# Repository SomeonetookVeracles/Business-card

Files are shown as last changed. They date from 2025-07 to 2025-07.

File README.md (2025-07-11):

# Business-card
A PCB business card with a USB-C port and HID, so when you press the button it auto opens a link to the website encoded on it.
I feel like in tech you really need to stand out when it comes to how you spread your information, so I decided to create a twist on the standard business card design by creating a HID business card to make employers expend that little bit of effort to remember me by.







### Bill of Materials

## Bill of Materials (BOM)

| Reference | Qty | Value | DNP | Exclude from BOM | Exclude from Board | Footprint | Datasheet/Purchase Links |
|---|-----|---|-----|---|---|---|---|
| C1, C2, C3, C4 | 4 | 1uF | | | | Capacitor_SMD:C_0201_0603Metric | [DigiKey 1µF 0603](https://www.digikey.com/en/products/detail/yageo/CC0603ZRY5V7BB105/2103110) • [Mouser 1µF 0603](https://www.mouser.com/c/passive-components/capacitors/ceramic-capacitors/mlccs-multilayer-ceramic-capacitors/multilayer-ceramic-capacitors-mlcc-smd-smt/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) • [LCSC Capacitors](https://lcsc.com/products/Capacitors_312.html) |
| C5 | 1 | 10uF | | | | Capacitor_SMD:C_0201_0603Metric | [DigiKey 10µF 0603](https://www.digikey.com/en/products/filter/ceramic-capacitors/60) • [Mouser 10µF](https://www.mouser.com/c/passive-components/capacitors/) • [LCSC Capacitors](https://lcsc.com/products/Capacitors_312.html) |
| C6, C7 | 2 | 22pF | | | | Capacitor_SMD:C_0201_0603Metric | [DigiKey 22pF 0603](https://www.digikey.com/en/products/filter/ceramic-capacitors/60) • [Mouser 22pF](https://www.mouser.com/c/passive-components/capacitors/) • [LCSC Capacitors](https://lcsc.com/products/Capacitors_312.html) |
| J3 | 1 | USB_C_Receptacle | | | | Connector_USB:USB_C_Receptacle_Amphenol_12401548E4-2A | [DigiKey 12401548E4#2A](https://www.digikey.com/en/products/detail/amphenol-cs-commercial-products/12401548E4-2A/5318158) • [USB Type-C Spec](https://www.usb.org/sites/default/files/documents/usb_type-c.zip) |
| R1 | 1 | 10k | | | | Resistor_SMD:R_0402_1005Metric_Pad0.72x0.64mm_HandSolder | [DigiKey 10kΩ 0402](https://www.digikey.com/en/products/filter/chip-resistor-surface-mount/52) • [Mouser 10kΩ](https://www.mouser.com/c/passive-components/resistors/) • [LCSC Resistors](https://lcsc.com/products/Chip-Resistor-Surface-Mount_439.html) |
| R2, R3 | 2 | 22 | | | | Resistor_SMD:R_0201_0603Metric | [DigiKey 22Ω 0603](https://www.digikey.com/en/products/filter/chip-resistor-surface-mount/52) • [Mouser 22Ω](https://www.mouser.com/c/passive-components/resistors/) • [LCSC Resistors](https://lcsc.com/products/Chip-Resistor-Surface-Mount_439.html) |
| R4, R5, R6, R7 | 4 | 10k | | | | Resistor_SMD:R_0201_0603Metric | [DigiKey 10kΩ 0603](https://www.digikey.com/en/products/filter/chip-resistor-surface-mount/52) • [Mouser 10kΩ](https://www.mouser.com/c/passive-components/resistors/) • [LCSC Resistors](https://lcsc.com/products/Chip-Resistor-Surface-Mount_439.html) |
| R11, R12 | 2 | 5.1k | | | | Resistor_SMD:R_0201_0603Metric | [DigiKey 5.1kΩ 0603](https://www.digikey.com/en/products/filter/chip-resistor-surface-mount/52) • [Mouser 5.1kΩ](https://www.mouser.com/c/passive-components/resistors/) • [LCSC Resistors](https://lcsc.com/products/Chip-Resistor-Surface-Mount_439.html) |
| RST1 | 1 | SW_Push | | | | Button_Switch_SMD:SW_Push_1P1T_NO_CK_KMR2 | [DigiKey KMR221GLFS](https://www.digikey.com/en/products/detail/c-k/KMR221GLFS/550472) • [Mouser KMR221GLFS](https://www.mouser.com/ProductDetail/CK/KMR221GLFS?qs=sb%2But3Lm4x2RtkMQYdEYMA%3D%3D) • [C&K KMR2 Series](https://www.ckswitches.com/products/switches/product-details/Tactile/KMR2/) |
| SW1, SW2, SW3 | 3 | SW_Omron_B3FS | | | | Button_Switch_SMD:SW_SPST_Omron_B3FS-100xP | [DigiKey B3FS-1000P](https://www.digikey.com/en/products/detail/omron-electronics-inc-emc-div/B3FS-1000P/277814) • [Mouser B3FS Series](https://www.mouser.com/new/omron-electronics/omronB3FS4/) • [Omron B3FS Datasheet](https://omronfs.omron.com/en_US/ecb/products/pdf/en-b3fs.pdf) |
| U1 | 1 | ATmega32U4-A | | | | Package_QFP:TQFP-44_10x10mm_P0.8mm | [DigiKey ATMEGA32U4-AU](https://www.digikey.com/en/products/detail/microchip-technology/ATMEGA32U4-AU/1914602) • [Mouser ATMEGA32U4-AUR](https://www.mouser.com/ProductDetail/Microchip-Technology/ATMEGA32U4-AUR?qs=rBGENRD8NwIbVIAimLns%252BA%3D%3D) • [ATmega32U4 Datasheet](http://ww1.microchip.com/downloads/en/DeviceDoc/Atmel-7766-8-bit-AVR-ATmega16U4-32U4_Datasheet.pdf) |
| Y1 | 1 | Crystal_GND24_Small| | | | Crystal:Crystal_SMD_0603-4Pin_6.0x3.5mm | [DigiKey 16MHz Crystal](https://www.digikey.com/en/products/detail/txc-corporation/7V-16-000MAAE-T/2626978) • [Mouser 16MHz SMD](https://www.mouser.com/c/passive-components/frequency-control-timing-devices/crystals/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) • [LCSC Crystals](https://lcsc.com/products) |

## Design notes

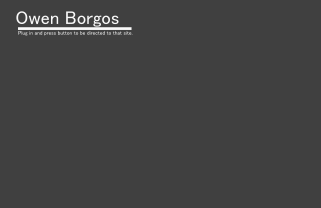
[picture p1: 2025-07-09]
Kicad Layer 1.png

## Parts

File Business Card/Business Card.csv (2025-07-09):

Reference | Qty | Value | DNP | Exclude from BOM | Exclude from Board | Footprint | Datasheet
C1,C2,C3,C4 | 4 | 1uF |  |  |  | Capacitor_SMD:C_0201_0603Metric | ~
C5 | 1 | 10uF |  |  |  | Capacitor_SMD:C_0201_0603Metric | ~
C6,C7 | 2 | 22pF |  |  |  | Capacitor_SMD:C_0201_0603Metric | ~
J3 | 1 | USB_C_Receptacle |  |  |  | Connector_USB:USB_C_Receptacle_Amphenol_12401548E4-2A | https://www.usb.org/sites/default/files/documents/usb_type-c.zip
R1 | 1 | 10k |  |  |  | Resistor_SMD:R_0402_1005Metric_Pad0.72x0.64mm_HandSolder | ~
R2,R3 | 2 | 22 |  |  |  | Resistor_SMD:R_0201_0603Metric | ~
R4,R5,R6,R7 | 4 | 10k |  |  |  | Resistor_SMD:R_0201_0603Metric | ~
R11,R12 | 2 | 5.1k |  |  |  | Resistor_SMD:R_0201_0603Metric | ~
RST1 | 1 | SW_Push |  |  |  | Button_Switch_SMD:SW_Push_1P1T_NO_CK_KMR2 | ~
SW1,SW2,SW3 | 3 | SW_Omron_B3FS |  |  |  | Button_Switch_SMD:SW_SPST_Omron_B3FS-100xP | https://omronfs.omron.com/en_US/ecb/products/pdf/en-b3fs.pdf
U1 | 1 | ATmega32U4-A |  |  |  | Package_QFP:TQFP-44_10x10mm_P0.8mm | http://ww1.microchip.com/downloads/en/DeviceDoc/Atmel-7766-8-bit-AVR-ATmega16U4-32U4_Datasheet.pdf
Y1 | 1 | Crystal_GND24_Small |  |  |  | Crystal:Crystal_SMD_0603-4Pin_6.0x3.5mm | ~

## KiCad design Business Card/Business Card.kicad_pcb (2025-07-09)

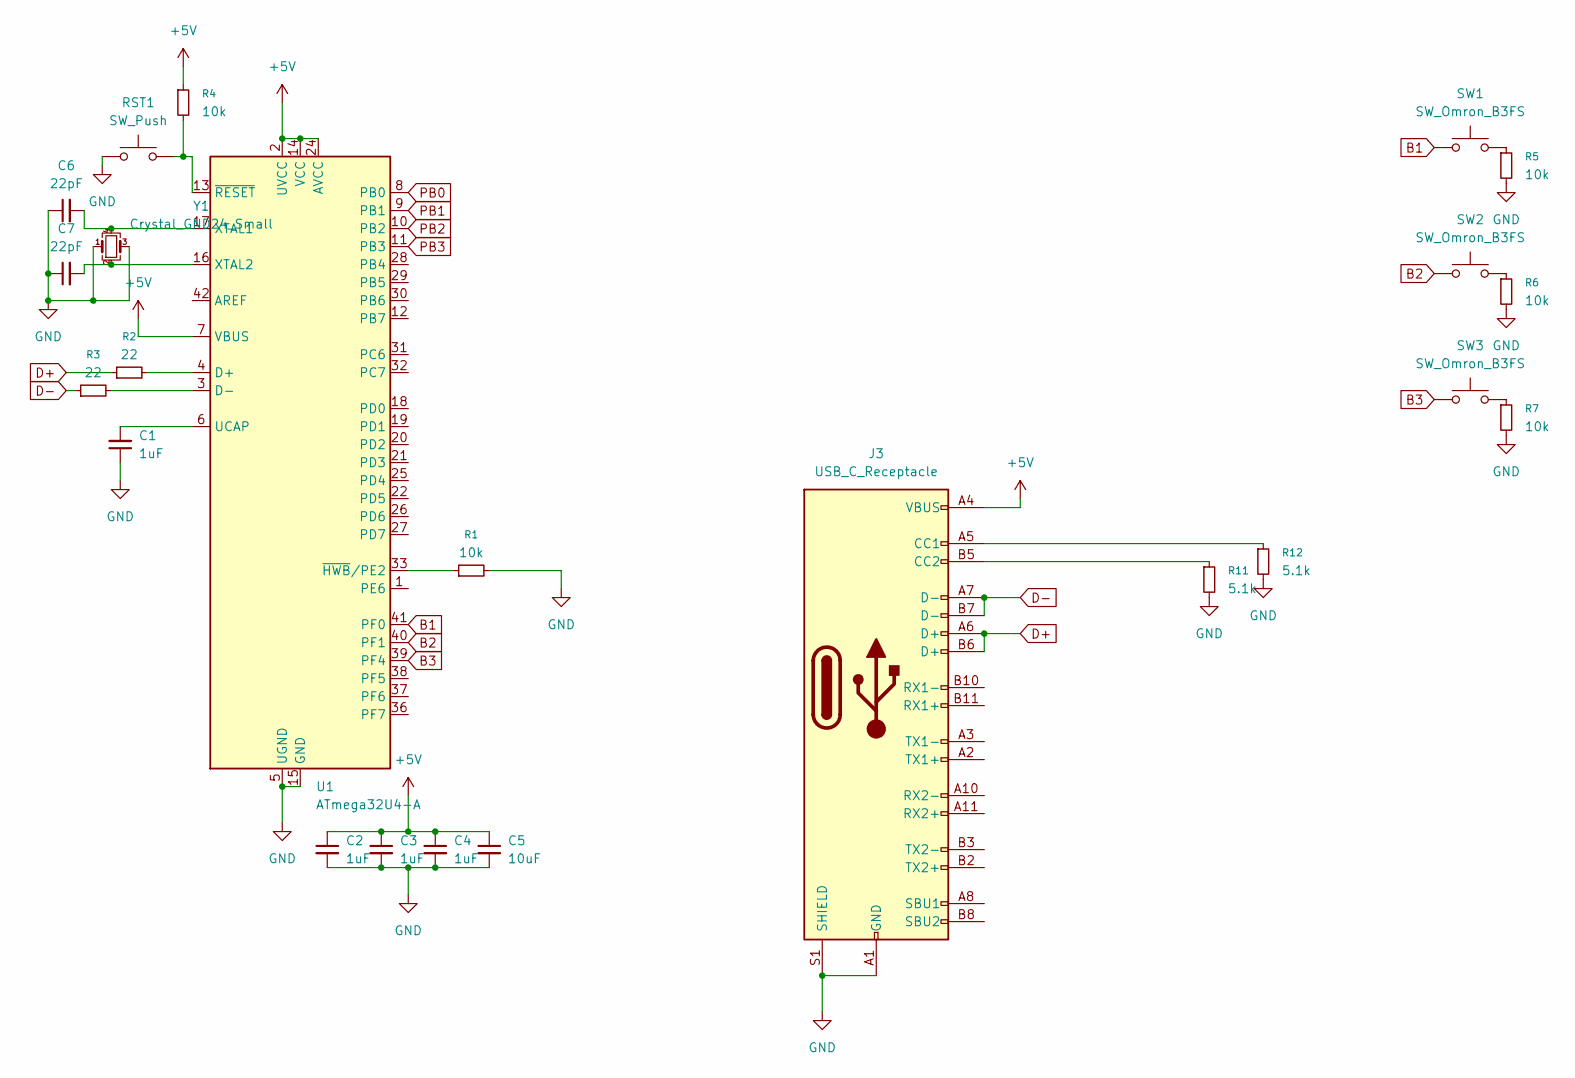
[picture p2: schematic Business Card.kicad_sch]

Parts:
C1, C2, C3, C4: 1uF; C_0201_0603Metric
C5: 10uF; C_0201_0603Metric
C6, C7: 22pF; C_0201_0603Metric
J3: USB_C_Receptacle; USB_C_Receptacle_Amphenol_12401548E4-2A
R1: 10k; R_0402_1005Metric_Pad0.72x0.64mm_HandSolder
R2, R3: 22; R_0201_0603Metric
R4, R5, R6, R7: 10k; R_0201_0603Metric
R11, R12: 5.1k; R_0201_0603Metric
RST1: SW_Push; SW_Push_1P1T_NO_CK_KMR2
SW1, SW2, SW3: SW_Omron_B3FS; SW_SPST_Omron_B3FS-100xP
U1: ATmega32U4-A; TQFP-44_10x10mm_P0.8mm
Y1: Crystal_GND24_Small; Crystal_SMD_0603-4Pin_6.0x3.5mm

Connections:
+5V: C2.1, C3.1, C4.1, C5.1, J3.A4 (VBUS), J3.A9 (VBUS), J3.B4 (VBUS), J3.B9 (VBUS), R4.1, U1.2 (UVCC), U1.7 (VBUS), U1.14 (VCC), U1.24 (AVCC), U1.34 (VCC), U1.44 (AVCC)
B1: SW1.1, U1.41 (PF0)
B2: SW2.1, U1.40 (PF1)
B3: SW3.1, U1.39 (PF4)
D+: J3.A6 (D+), J3.B6 (D+), R2.1
D-: J3.A7 (D-), J3.B7 (D-), R3.1
GND: C1.1, C2.2, C3.2, C4.2, C5.2, C6.1, C7.1, J3.A1 (GND), J3.A12 (GND), J3.B1 (GND), J3.B12 (GND), J3.S1 (SHIELD), R1.2, R5.2, R6.2, R7.2, R11.2, R12.2, RST1.1, U1.5 (UGND), U1.15 (GND), U1.23 (GND), U1.35 (GND), U1.43 (GND), Y1.1, Y1.3
unnamed: J3.A5 (CC1), R12.1
unnamed: J3.B5 (CC2), R11.1
unnamed: R5.1, SW1.2
unnamed: R6.1, SW2.2
unnamed: R7.1, SW3.2
unnamed: R2.2, U1.4 (D+)
unnamed: R3.2, U1.3 (D-)
unnamed: C1.2, U1.6 (UCAP)
unnamed: C6.2, U1.17 (XTAL1), Y1.4
unnamed: C7.2, U1.16 (XTAL2), Y1.2
unnamed: R1.1, U1.33 (~HWB/PE2)
unnamed: R4.2, RST1.2, U1.13 (~RESET)
PB0: U1.8 (PB0)
PB1: U1.9 (PB1)
PB2: U1.10 (PB2)
PB3: U1.11 (PB3)

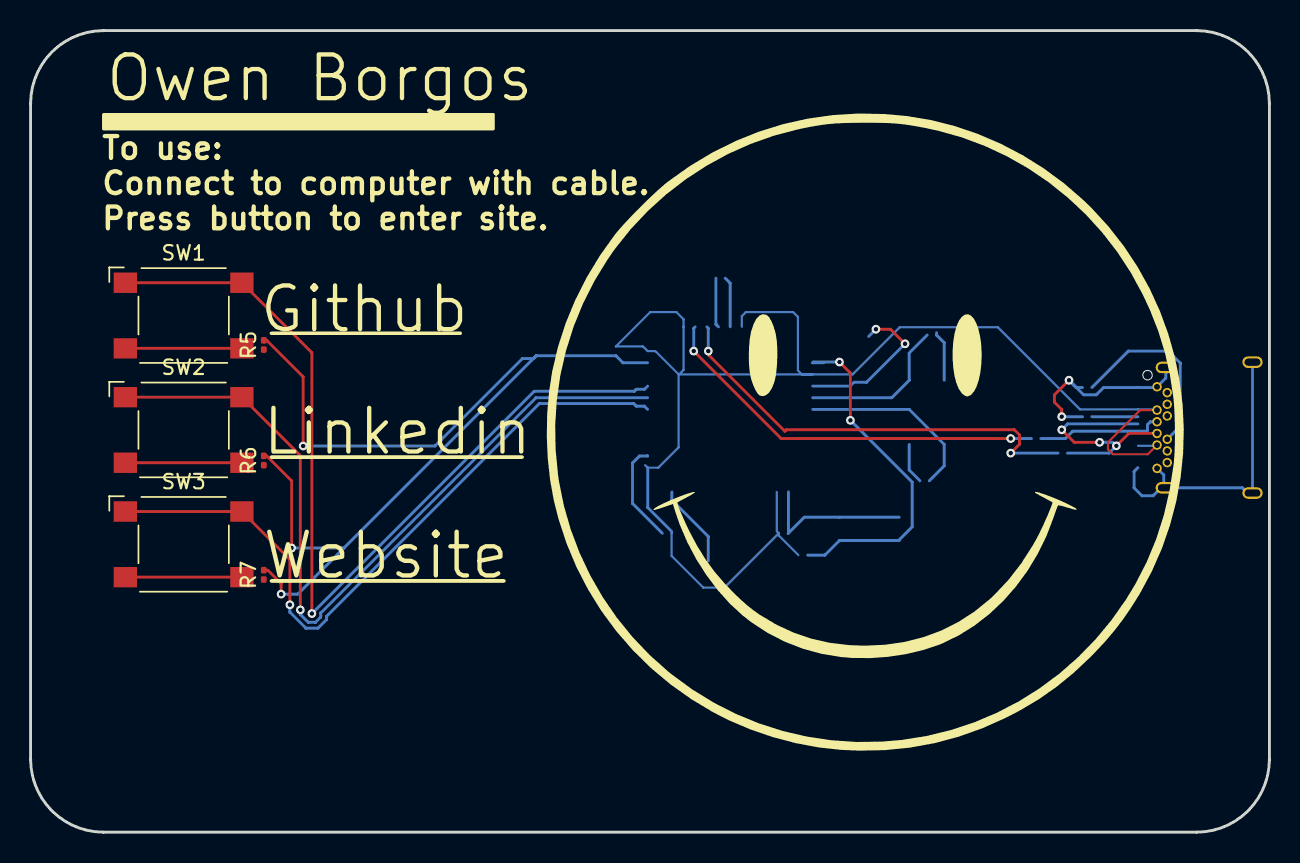
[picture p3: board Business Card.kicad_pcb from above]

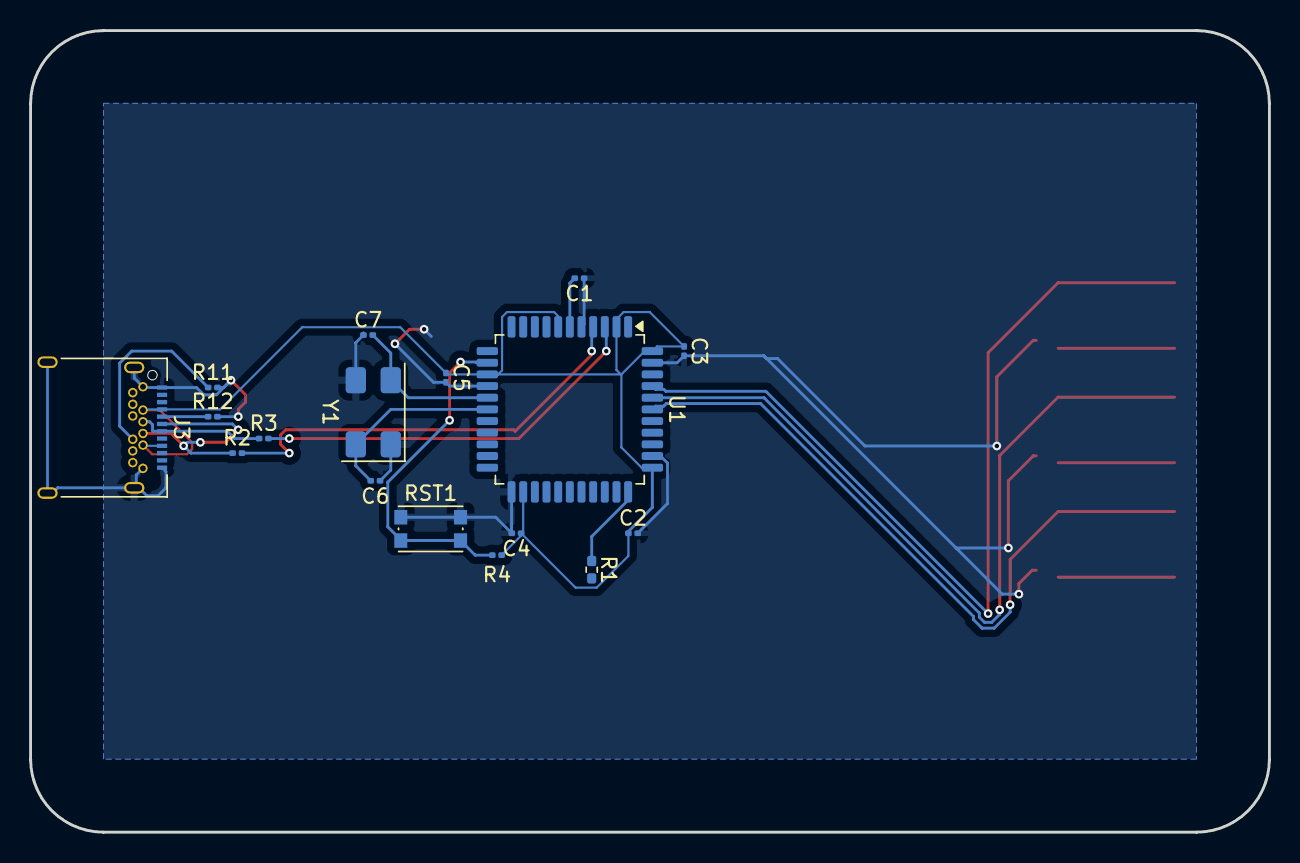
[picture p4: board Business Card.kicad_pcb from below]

Board: 2 copper layers, 85.0 x 55.0 mm, 23 parts (17 on the bottom side), 19 nets.

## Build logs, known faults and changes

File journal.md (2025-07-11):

# Total time spent: 5 hours
---
title: "Smart Business Card"
author: "Veracles"
description: "A business card for my personal site, and info, with a HID setup so they can access my website with a button push"
created_at: "2025-07-08"
---
# July 8th
I created the schematic for the business card, and the MCU. I struggled a lot with the chip itself, because crystals (XTAL) have to be routed equally, which sucks. My initial plan was a XOR gate, but I think it would be noot complicated enough, so I'm swapping to a HID device on arduino atmega32u4, with buttons, because it honestly seems more fun.



Initial schematic, I fiddled a bit with a rasperry pi pico and Arduino Nano, but ultimately went with a normal MCU due to space requirements and my own ego. The initial plan was to make a bare MCU, but it ended up frustrating me because of the previously mentioned crystal issue, so I tried to go with a devboard, but they were either too expensive or not complex enough technically for what I needed. I tried the Arduino Nano, SMD edition, but it was too big for what I needed. I also did the Pico, but it didn't like me using the GPIO for data transfer for the USB-C, because, say with with me: **USB-C is evil, and my hatred for it is biblical**.


Couldn't find a good USB c footprint so I had to use a different library, good lord USB-C is an evil format, for evil people. Honestly 

**Total time spent: 2 Hours**
# July 9th
I made the PCB, and got it wired up, I struggled with implementing ground planes, and you ccan see that the USB c pins are difficult because of the size of the traces I'm doing for the GND and +5v nets (to avoid a funny mistake) I'll add the silkscreen after I eat lunch. 



Done! Lunch was very tasty, I spent a like 30 minutes on a silkscreen in inkscape, but lost all my footage, so I have the final result below, but I added the buttons and the details (my phone number is on there too, but I redacted for obvious reasons). It's easy enough to code, as each of the buttons is wired to a GPIO pin with a pull down resistor to the ground plane.



** Total Time spent: 5 Hours**

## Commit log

2025-07-09 FORGOT TO COMMIT FUCK
    FUCK FUCK FUCK
    [Business Card.csv, Business Card.kicad_pcb, Business Card.kicad_sch]
2025-07-11 Added links to BOM
